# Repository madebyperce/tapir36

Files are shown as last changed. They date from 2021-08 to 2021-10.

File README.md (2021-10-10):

# tapir36
Minimally MX-spaced reversible ergo split board

## Updates
Rev 1.1 has: 
* Updated diode footprint silkscreen -- easier to understand diode direction
* Updated MCU silkscreen -- easier to understand which set of holes to solder
* Moved MCU and TRRS female jack receiver up to resolve desing issue of PCB in way of TRRS jack
* Added reset switch pads
* Simplified Tapir art 
* Increased font size of text

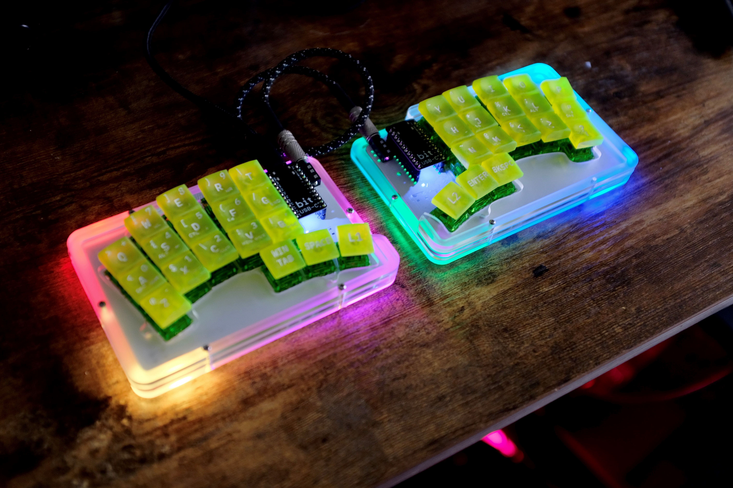
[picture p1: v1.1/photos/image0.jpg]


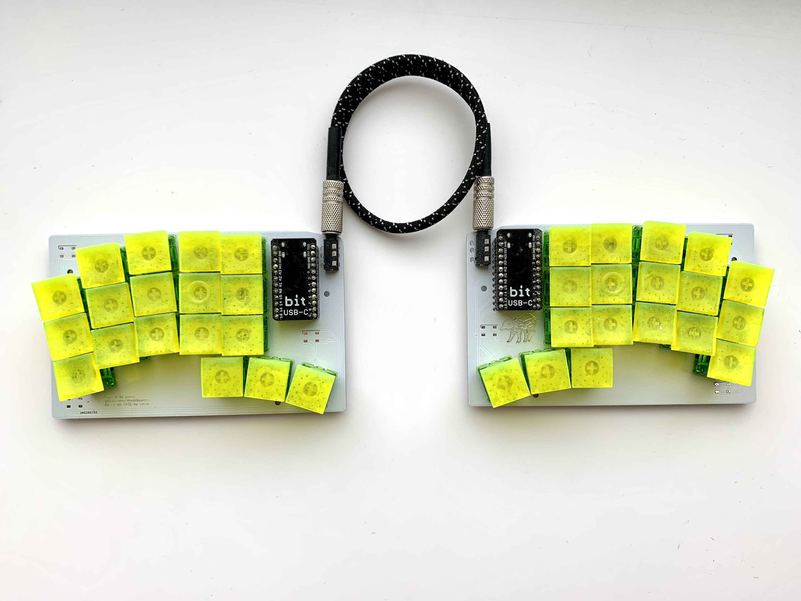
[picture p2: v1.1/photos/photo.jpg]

 
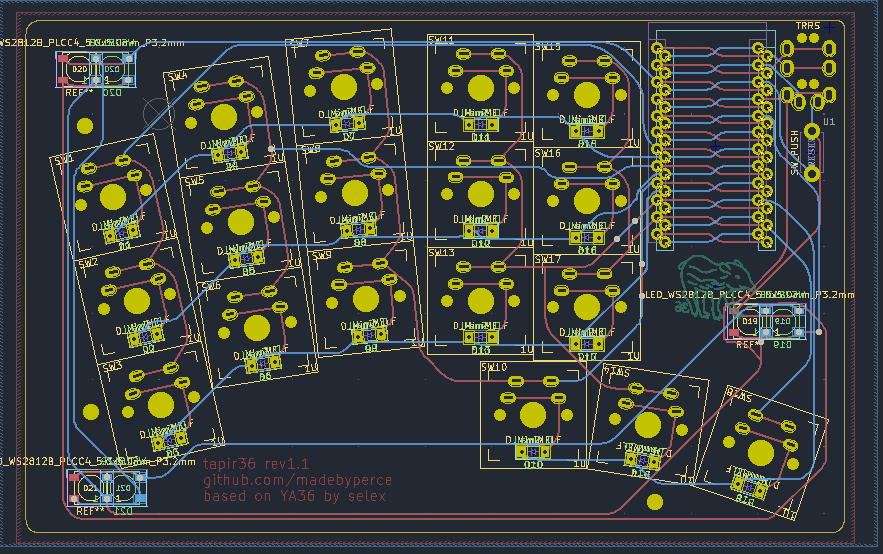
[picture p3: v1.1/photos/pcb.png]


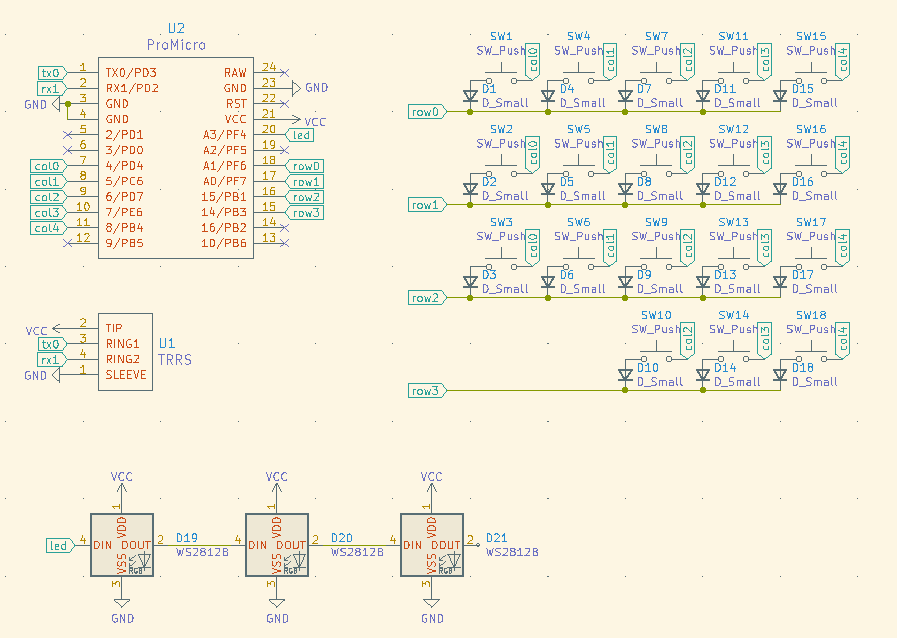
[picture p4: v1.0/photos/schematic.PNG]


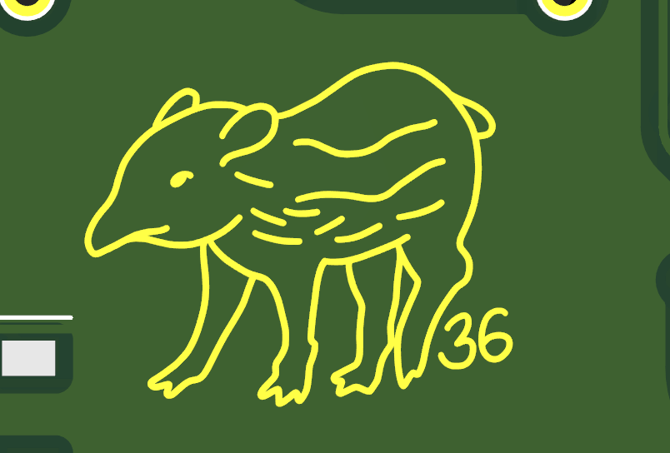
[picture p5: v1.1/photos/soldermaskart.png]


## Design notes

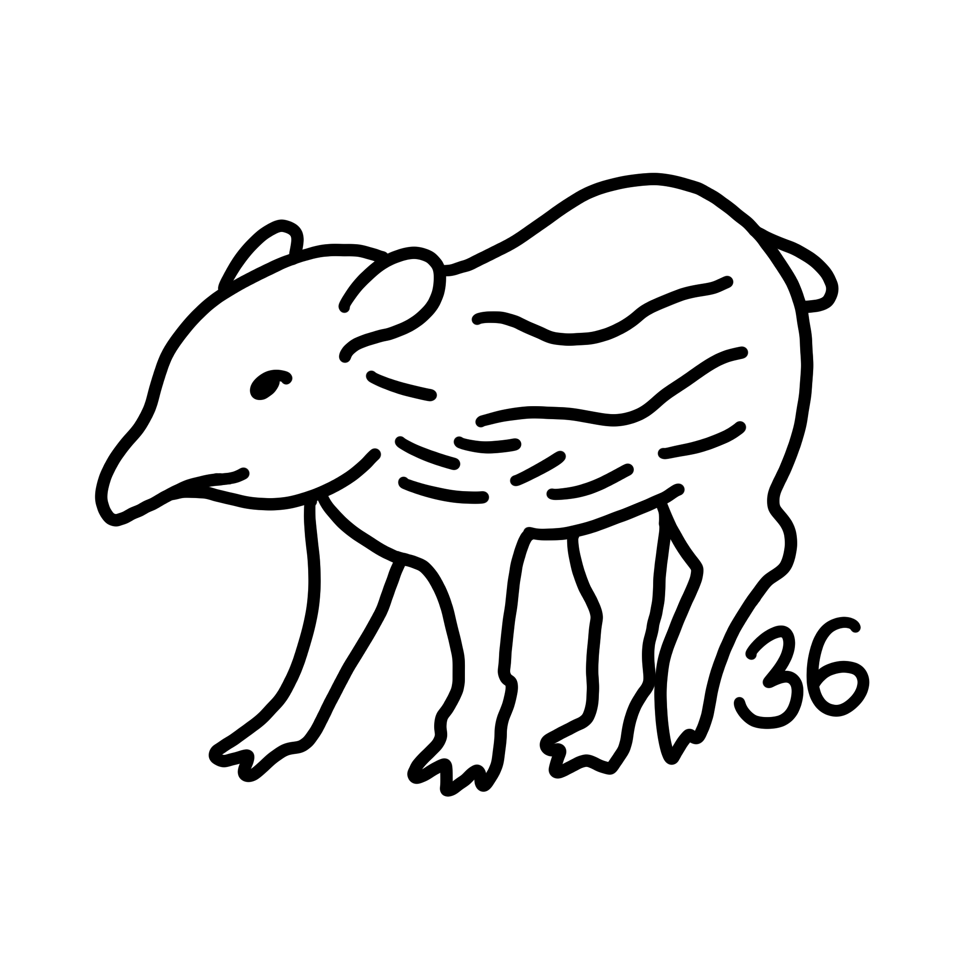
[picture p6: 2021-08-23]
v1.1/kicad/tapir.png

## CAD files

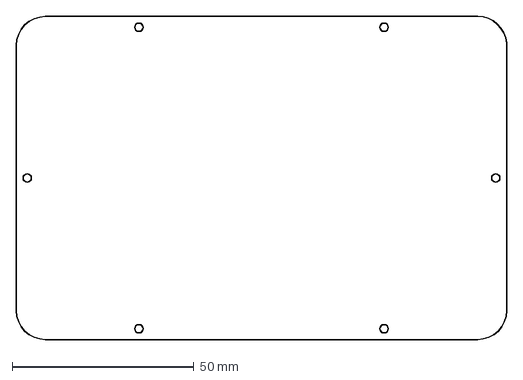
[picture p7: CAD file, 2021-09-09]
acrylic case/layer 1.dxf
135.0 x 89.0 mm

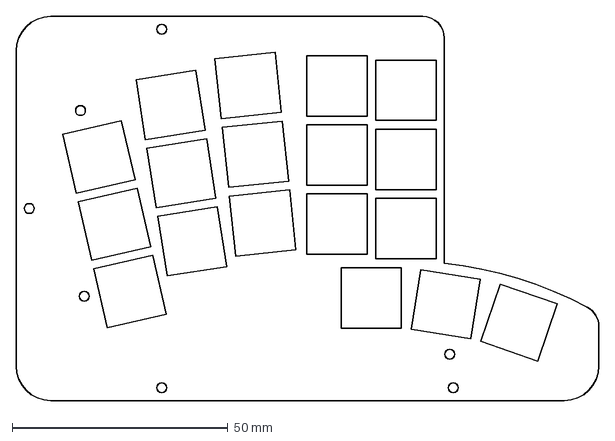
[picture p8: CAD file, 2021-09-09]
acrylic case/plate.dxf
135.0 x 89.0 mm

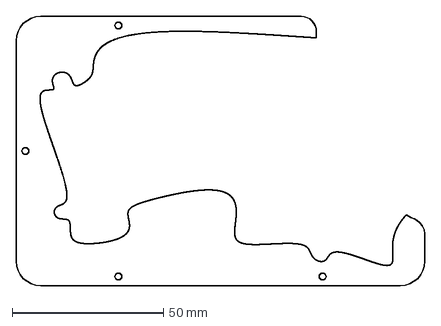
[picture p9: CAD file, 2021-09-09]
acrylic case/layer 4.dxf
135.0 x 89.0 mm

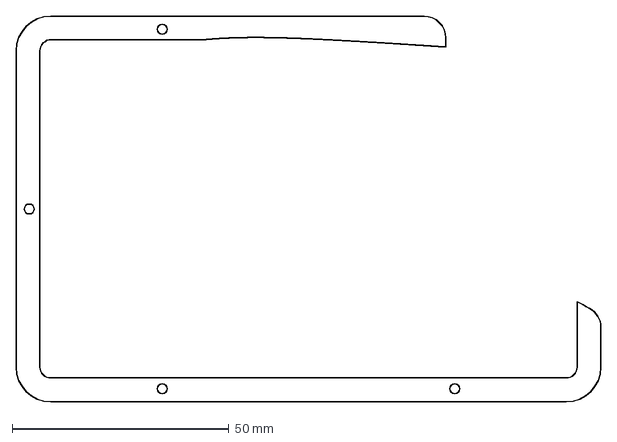
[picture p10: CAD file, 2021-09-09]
acrylic case/layer 3.dxf
135.0 x 89.0 mm

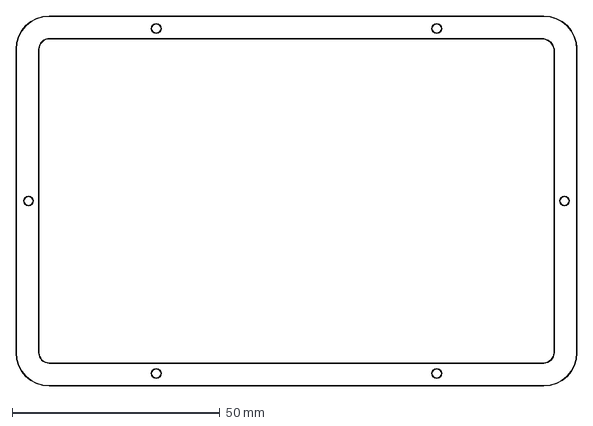
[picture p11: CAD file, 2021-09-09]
acrylic case/layer 2.dxf
135.0 x 89.0 mm

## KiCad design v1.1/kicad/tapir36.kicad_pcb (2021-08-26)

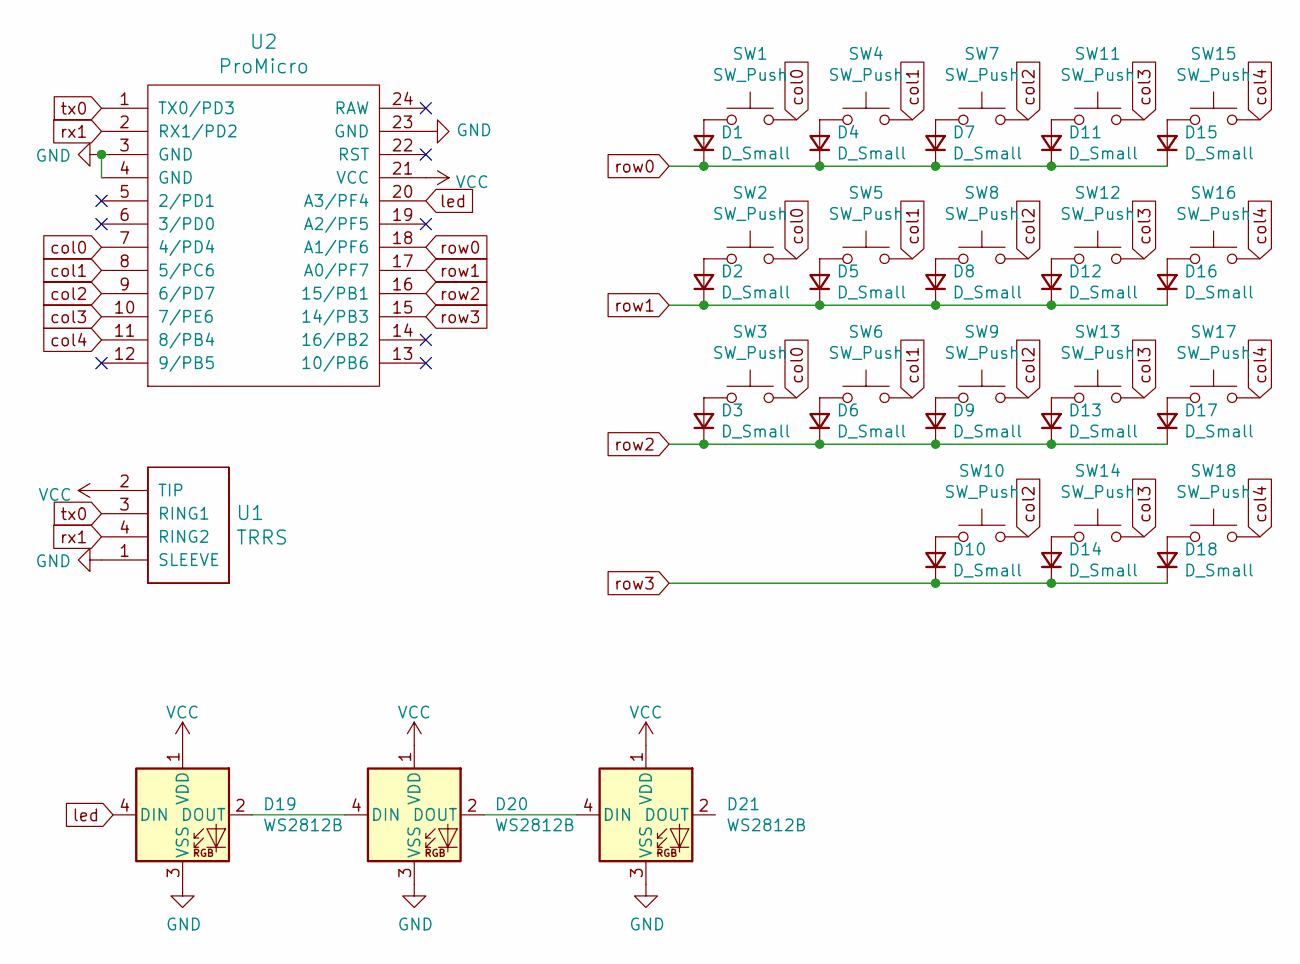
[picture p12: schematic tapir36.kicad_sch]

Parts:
D1, D2, D3, D4, D5, D6, D7, D8, D9, D10, D11, D12, D13, D14, D15, D16, D17, D18: D_Small; D_MiniMELF-DoubleSide
D19, D20, D21: WS2812B; LED_WS2812B_PLCC4_5.0x5.0mm_P3.2mm
SW1, SW2, SW3, SW4, SW5, SW6, SW7, SW8, SW9, SW10, SW11, SW12, SW13, SW14, SW15, SW16, SW17, SW18: SW_Push; MX-reversible-min-spacing
U1: TRRS; TRRS-PJ-320A-dual_slim
U2: ProMicro; ReversibleProMicro

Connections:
GND: D19.3 (VSS), D20.3 (VSS), D21.3 (VSS), U1.1 (SLEEVE), U2.3 (GND), U2.4 (GND), U2.23 (GND); also elsewhere on the board
unnamed: D1.2 (A), SW1.1
unnamed: D2.2 (A), SW2.1
unnamed: D3.2 (A), SW3.1
unnamed: D4.2 (A), SW4.1
unnamed: D5.2 (A), SW5.1
unnamed: D6.2 (A), SW6.1
unnamed: D7.2 (A), SW7.1
unnamed: D8.2 (A), SW8.1
unnamed: D9.2 (A), SW9.1
unnamed: D10.2 (A), SW10.1
unnamed: D11.2 (A), SW11.1
unnamed: D12.2 (A), SW12.1
unnamed: D13.2 (A), SW13.1
unnamed: D14.2 (A), SW14.1
unnamed: D15.2 (A), SW15.1
unnamed: D16.2 (A), SW16.1
unnamed: D17.2 (A), SW17.1
unnamed: D18.2 (A), SW18.1
unnamed: D19.2 (DOUT), D20.4 (DIN)
unnamed: D20.2 (DOUT), D21.4 (DIN)
col0: SW1.2, SW2.2, SW3.2, U2.7 (4/PD4)
col1: SW4.2, SW5.2, SW6.2, U2.8 (5/PC6)
col2: SW7.2, SW8.2, SW9.2, SW10.2, U2.9 (6/PD7)
col3: SW11.2, SW12.2, SW13.2, SW14.2, U2.10 (7/PE6)
col4: SW15.2, SW16.2, SW17.2, SW18.2, U2.11 (8/PB4)
led: D19.4 (DIN), U2.20 (A3/PF4)
row0: D1.1 (K), D4.1 (K), D7.1 (K), D11.1 (K), D15.1 (K), U2.18 (A1/PF6)
row1: D2.1 (K), D5.1 (K), D8.1 (K), D12.1 (K), D16.1 (K), U2.17 (A0/PF7)
row2: D3.1 (K), D6.1 (K), D9.1 (K), D13.1 (K), D17.1 (K), U2.16 (15/PB1)
row3: D10.1 (K), D14.1 (K), D18.1 (K), U2.15 (14/PB3)
rx1: U1.4 (RING2), U2.2 (RX1/PD2)
tx0: U1.3 (RING1), U2.1 (TX0/PD3)
vcc: D19.1 (VDD), D20.1 (VDD), D21.1 (VDD), U1.2 (TIP), U2.21 (VCC)

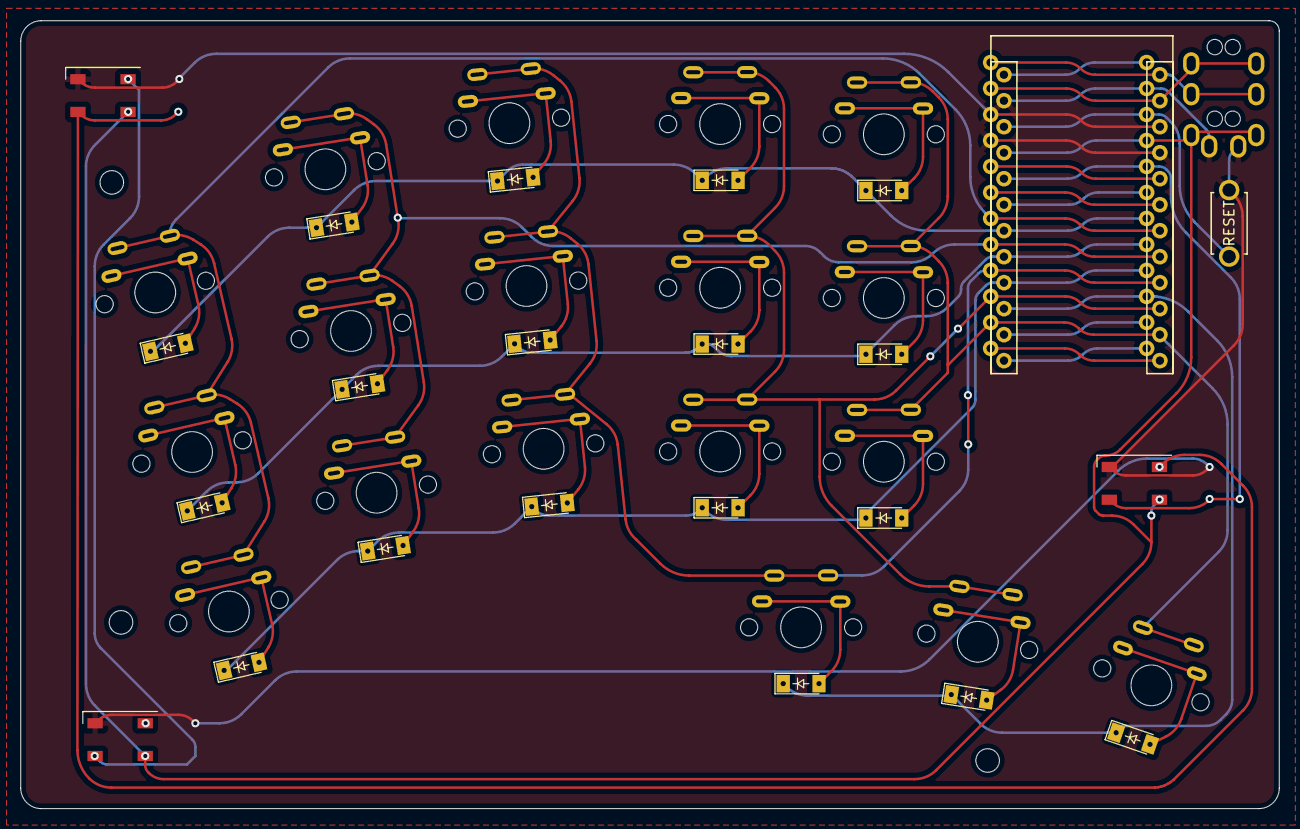
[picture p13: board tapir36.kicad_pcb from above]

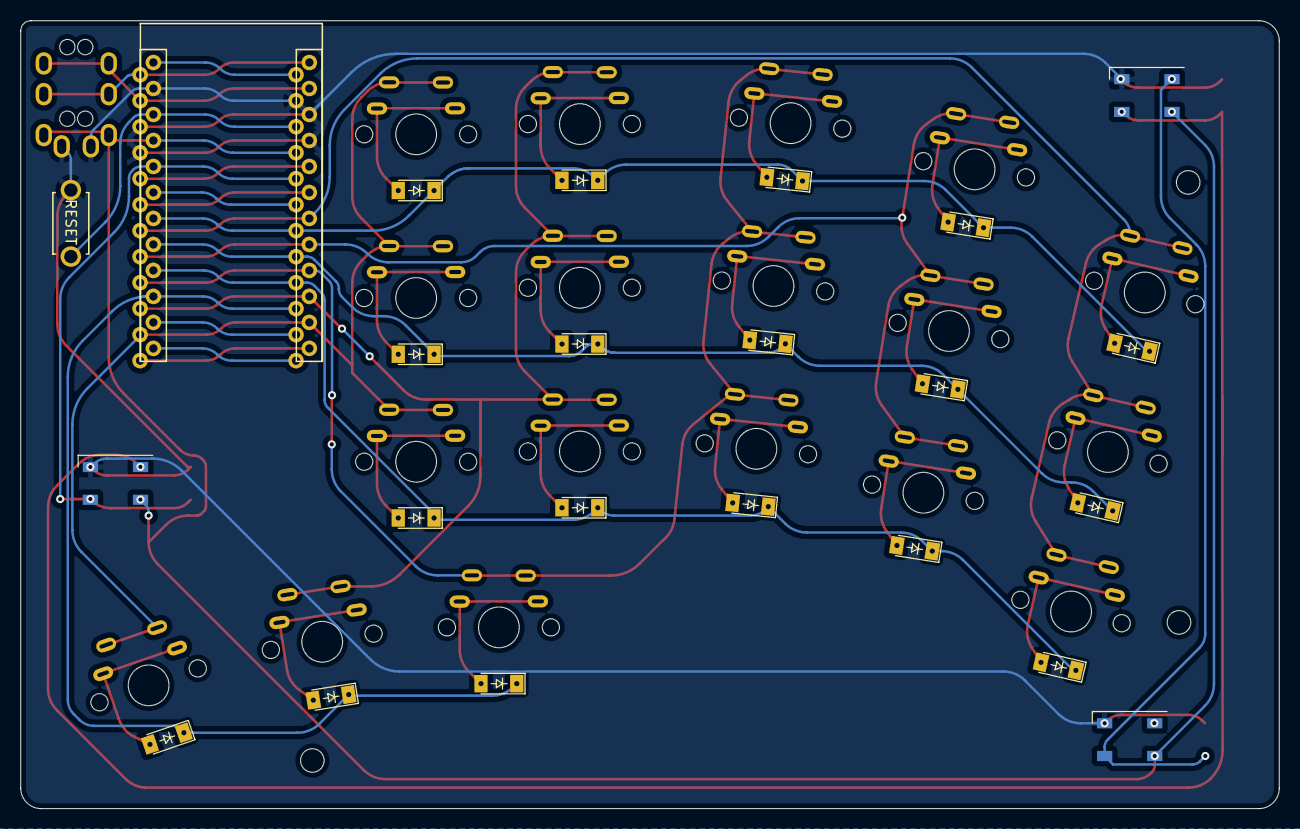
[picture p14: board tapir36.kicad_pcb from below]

Board: 2 copper layers, 123.0 x 77.0 mm, 43 parts (21 on the bottom side), 34 nets.

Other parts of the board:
RSW1: SW_PUSH; ResetSW
Ref**: Val**; thread_m2

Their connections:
GND: RSW1.1; also elsewhere on the board

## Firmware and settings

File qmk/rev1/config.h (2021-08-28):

#pragma once


/* USB Device descriptor parameter */
#define VENDOR_ID       0x0000
#define PRODUCT_ID      0x0000
#define DEVICE_VER      0x0001
#define MANUFACTURER    perce
#define PRODUCT         tapir36

#define MATRIX_ROWS 8
#define MATRIX_COLS 5

// wiring
#define MATRIX_ROW_PINS { F6, F7, B1, B3 }
#define MATRIX_COL_PINS { D4, C6, D7, E6, B4 }
#define MATRIX_ROW_PINS_RIGHT { F6, F7, B1, B3 }
#define MATRIX_COL_PINS_RIGHT { B4, E6, D7, C6, D4 }

#define SOFT_SERIAL_PIN D2
#define SPLIT_USB_DETECT

/* COL2ROW, ROW2COL*/
#define DIODE_DIRECTION COL2ROW

/* Debounce reduces chatter (unintended double-presses) - set 0 if debouncing is not needed */
#define DEBOUNCE 5

#define RGB_DI_PIN F4
#define RGBLED_NUM 6
#define RGBLED_SPLIT {3,3}
#define RGBLIGHT_ANIMATIONS
#define RGBLIGHT_LIMIT_VAL 128

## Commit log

2021-08-10 update with proper naming
    [tapir36.kicad_pcb, tapir36.kicad_sch]
2021-08-10 fix vcc flags lmao
    [tapir36.kicad_sch]
2021-08-23 update with v1.1
    [tapir36-B_Cu.gbr, tapir36-B_Mask.gbr, tapir36-B_Paste.gbr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]
2021-09-09 add case
    [layer 1.dxf, layer 2.dxf, layer 3.dxf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]
